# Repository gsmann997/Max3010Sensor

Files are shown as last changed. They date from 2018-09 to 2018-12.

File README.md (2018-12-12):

# Max3010Sensor Build Instruction
# Table of content
1. [Introduction](#introdution)
2. [Parts Required](#parts-required)
3. [Time Commitment](#time-commitment)
4. [OS image and sensor testing](#os-image-and-sensor-testing)
5. [Testing and Pins Soldering](#testing-and-pins-soldering)
6. [Max30105 Electronic File Design](#max30105-electronic-file-design)
7. [Assembly](#assembly)
8. [Code Testing](#code-testing)
9. [Case design and Assembly](#case-design-and-assembly)
10. [Testing](#testing)
<!--
<p>
<img src="https://user-images.githubusercontent.com/43187603/48815301-07242580-ed0c-11e8-836c-ad78ff526679.jpg" heigth=300 width=450>
<p> -->
  img-20181120-wa0004

# Introduction

diagram

This project is based on the MAX30105, which is a very powerful sensor (it can sense the distance, heart rate, particle in the air and even the blinking of an eye)
For this particular project I decided to implement only the heart rate functionality.
It is important that you read the <a href="https://cdn.sparkfun.com/assets/learn_tutorials/5/7/7/MAX30105_3.pdf">datasheet</a> of the sensor before any different connection than the one shown below are done.
For the project I am using the raspberry Pi as microcontroller, as I am already familiar on how it works.
The Max30105 has three on-board LEDs: green, red and IR which works on 5v but the sensor can work on 3.3V as well, as if 5V are applied to the raspberry pi, the GPIO will break.
Below, all the required material, assembly steps and code testing are explained. All the data below has been tested and tried and is the result of many failied attempt. 
It should not take you more than 3h to do everything supposing that you have all the required material.<br>
# Parts required
The Parts required are (click on the product to be redicted where I bought the items, but feel free to buy them from anywhere more convenient to you):
<ul>
  <li><a href="https://www.canakit.com/raspberry-pi-3-model-b-plus-ultimate-kit.html">Raspberry Pi</a></li>
  <li><a href="https://www.amazon.ca/Sandisk-Ultra-Micro-UHS-I-Adapter/dp/B073K14CVB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">Sd card (minimum 8GB)</a></li>
<li><a href="https://www.sparkfun.com/products/14045"> Max30105</a></li>
<li> <a href="https://www.amazon.ca/Haobase-120pcs-Multicolored-Female-Breadboard/dp/B01DLKLL6C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
"> Male to female wires</a></li>
  <li>PCB (my PCB was printed by the <a href="http://munro.humber.ca/~mdrk0011/">prototype lab at Humber College</a> so feel free to use the method more convenient to you)</li>
  <li><a href="https://www.digikey.ca/products/en?keywords=SAM9289-ND">5 Header</a> <a href="https://www.digikey.ca/product-detail/en/sullins-connector-solutions/PPTC051LFBN-RC/S6103-ND/807239">and 6 pin header</a></li>
</ul>
 I spent around 119$ on the parts (<a href="https://github.com/gsmann997/Max3010Sensor/blob/master/documents/budget.xlsx">click here to download my budget</a>). Moreover, consider that it will take around 3/4 weeks to receive the parts, so please take extra time to order and receive the parts.
  
  # Time Commitment
  
  Once you receive that parts (included the PCB), it should take you around 5 hour to do the testing, mechanical assembly and power up.
  Please reference to my <a href= "https://github.com/gsmann997/Max3010Sensor/blob/master/documents/schedule.pdf">time commitment</a> and how I divided the work through 4 months. 
  However, it should not take this much time as I am supplying all required material and a detail guide to follow.
  
  # OS image and sensor testing
Once you received the Raspberry Pi and micro sd, you can proceed to install an OS in the PI.
To install the OS in the PI, reference to <a href="https://github.com/six0four/StudentSenseHat/blob/master/README.md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" >this link </a>, which cointains a detailed guide on how to install an OS in the Pi and has been given to us by our professor.
The second step, after the installion of the OS, is to make the PI accessible either via VNC (<a href="">click here to download vnc for Windows</a>). Activating VNC on the PI does not require much time, I used a guide on 
<a href="https://www.lynda.com/Raspberry-Pi-tutorials/Raspberry-Pi-Essential-Training/667376-2.html">lynda.com</a>, but if you do not have access to lynda.com use any resource.
# Testing and Pins Soldering

Before testing the sensor you need to solder the pins to the sensors. Moreover, before starting any soldering watch <a href="https://www.youtube.com/watch?v=BLfXXRfRIzY&list=PLQ32vZrF5U2lFOJTtZDytBWBYVLNp4RYz"> soldering videos </a> and <a href="https://safety.eng.cam.ac.uk/safe-working/copy_of_soldering-safety"> read risk assessments and chemical safety information</a>
Once you are reading for the soldering, solder the sensor with the pins.
The last step is breadbording and testing the connection/sensor and if every part is working fine.
Follow the wiring diagram below of the wiring:
<div>

</div>
Your breadbord should look like the image below:
<div>

</div>

Once the wiring is done, turn on the pi, enable I2C from options.
Furthermore, open the command terminal and run the following command: <b> i2cdetect -y -1</b><br>
On the screen you should be able to see the address of your sensor, this is a quick test to check if all the wiring has been done properly.
Example of screen:
  
 
# Max30105 Electronic File Design
The final project expects the sensor and the PI to be connected to each other through a PCB. 
I designed my PCB using <a href="http://fritzing.org/download/">fritzing </a>, here you can find <a href="https://github.com/gsmann997/Max3010Sensor/blob/master/documents/myPcb.fzz">my fritzing design</a> and <a href="https://github.com/gsmann997/Max3010Sensor/blob/master/documents/pcb_gerber.zip" >here you can find the gerber file of the PCB</a><br>This is the PCB diagram:

<div>

</div>

Once you get the PCB, you can solder the pins header to the PCB.
This is the final result:

<div>
  
</div> 

# Assembly
Once you receive the PCB, assemble everything:



Then, test it again as you did with the breadboarding <a href="#testing-and-pins-soldering">click here to see the steps again</a>.
# Code Testing
Until now, we have focused only on the hardware part, but we have also to work on the software part.
For the coding part, I used the MAX30102 libraries as I did need only the heart beat and not the other functionality of the sensor.
I have the code uploaded on my github and I am also posting the source code from where I initially retrived it.(
<a href="https://github.com/vrano714/max30102-tutorial-raspberrypi">click here to retrive the code</a> or <a href="https://github.com/gsmann997/Max3010Sensor/tree/master/files">click here for the source code on my github</a>)
Once you upload the code on your raspberry pi, run the max30102.py file with python3 compile option to execute the file and get the RED and IR LED.
# Case design and Assembly
Once the software side is complete the only step remaining is to make and assemble the case.
For the design of the case I used  [CorelDRAW Graphics Suite](https://www.coreldraw.com/en/?link=wm) and you can retrive the design [from here](https://github.com/gsmann997/Max3010Sensor/blob/master/documents/Pi2Case_default.cdr).<br>
Picture of the CorelDraw:<br> 
Once you get the case the only step left is assembling the case.
The final result is:

# Testing
To test if everything works, you can run the code on the PI and verify if the result is acceptable or there are some errors in the output.
As if we try to move this project in a production environment we will need to order everything in bulk which will make everything cheaper, specially the shipping cost. 
To make the production faster we can use one working image and clone it in the other new projects. Moreover, we can check regularly after a number of produced device if the image is working fine and has not been corrupted.
We can automate the soldering and assemblying process. Another improvement could be changing the design of the case and make it easier to assemble. Regarding the case it might be a better option to get it done by an external supplier, instead of buying the raw plastics and using the laser cut to make it.

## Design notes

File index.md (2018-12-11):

# Table of content
1. [week 2](#week-2)
2. [week 3](#week-3)
3. <a href='#week-4'> week 4</a>
4. [week 5](#week-5)
5. [week 7](#week-7)
6. [week 8](#week-8)
7. [week 9](#week-9)
8. [week 10](#week-10)
9. [week 11](#week-11)
10. [week 12](#week-12)
11. [week 13](#week-13)

#### Max3010Sensor
This file contains data for a project involving the Max3010x sensor
## Week 13
The presentation can be found [here](https://github.com/gsmann997/Max3010Sensor/blob/master/documents/MAX30105_presentation.pptx)
## Week 12
This week was due the enclosure.
For this week we had to design and prepare a case for our PI and sensor. To design my case I used [CorelDRAW Graphics Suite](https://www.coreldraw.com/en/?link=wm). After watching some tutorial on how to use the software I was able to modify the sample CorelDraw file ([click here to open it](https://github.com/gsmann997/Max3010Sensor/blob/master/documents/Pi2Case_default.cdr))  our teacher provided for the design.
After I printed the case I noticed that my PCB was overlapping with one side of the case, so I re-cut it with Vlad's help.
Unfortunately, while I was putting it together, I broke the plastic pins that are used to clip in each part of the case, so I had to reprint it again.
Then while I was assembling the new case I accidentaly broke it again. So the next day, I noticed that I was breaking it because of small design issues. After fixing the CorelDraw file and printing it again, finally I put everything together.
Picture of my CorelDraw:
crd
<br><br>Final Design:
img-20181120-wa0004

## Week 11
This week was due the power up milestone.
Unfortunately, as explained in last week posting I was already running late on my [schedule]( https://github.com/gsmann997/Max3010Sensor/blob/master/documents/schedule.pdf) and I have not been able to meet the deadline.
I tried to look up libraries for the integration of my sensor and the Pi but I was not able find anything.
The next step I took was looking up code online to get an idea of the type of code I need to write for my sensor.
However, not being familiar with this type of task made the whole process slower and time consuming.
So after I wrote my code, I tested it and unfortunatly It was not working. 
Then I tried to change approach, therefore I read the arduino libraries to get an idea of what I need but it has not been helpful.
In class I consulted the teacher and he advised me to take a smaller step and try to turn on the read LED on the sensor and look up all the register on the [datasheet](https://cdn.sparkfun.com/assets/learn_tutorials/5/7/7/MAX30105_3.pdf) of the sensor.
Moreover, I wrote some testing code but the reading on the screen was 0 and was not changing which meant It was not working.
After, I asked the teacher what I could do to fix the problem.
He advised me to test the code on another sensor: PCF8591.
Now, my next goals are going to be: learn how to push/ pull data from/to the PCF8591, write the code for the max30105 to get the readings within next week.
Regarding the [budget](https://github.com/gsmann997/Max3010Sensor/documents/budget.xlsx) no extra expenses where made.

# Update: 
After consulting Vlad from the prototype lab I decided to keep working on my sensor before trying to use the PCF8591, and after a couple more hours of research I find out that the previous version of my sensor (MAX30102) and the one I am using (MAX30105) are compatible.
The only difference between the two version is the fact that the older one does not have the green LED. However, the heart beat reading are calculated from the RED and IR LED.
After a couple more hours I was able to find a compatible library for my sensor on github([click here to retrive the code](https://github.com/vrano714/max30102-tutorial-raspberrypi) or [click here for the source code on my github](https://github.com/gsmann997/Max3010Sensor/tree/master/files)). Therefore, I installed and run the code.
Conclusion: I have been able to pull data from my sensor, but I still have to make the code I got mine.<br>
Next Goal: <br>   - Send the case to the prototype lab
           <br>   - Get ready for next week enclosure
<br>Below are the pictures of the code I run:<br><br>
redlog
<br><br>This are the readings I get from the RED LED<br><br>
irlog
<br><br>This are the readings I get from the IR LED<br><br>
graph
<br><br>Included in the files I got online, there was also a file to graph the two readings from the sensor.<br><br>

## Week 10
This week was due the PCB soldering. As advised by our teacher, I soldered headers to my PCB instead of soldering my sensor and the PI directly to the PCB, as if the PCB would not have worked I could have replaced the PCB instead of unsoldering everything.
Regarding the headers, in my last week posting I mentioned that I would be reaching out Kelly from the prototype lab for the headers. However, even though he provided me the headers for free, he did not have the 6x2 and 5x1 pin headers so he gave me bigger ones. 
Fortunately, I was able cut both the headers to fit my requirements.
My [budget](https://github.com/gsmann997/Max3010Sensor/documents/budget.xlsx)  did not see major changes thanks to the help of the prototype lab.
So my final result is:
pcb
pi pcb

The next step after the soldering is testing. 
I tested the PCB using the i2c detect command and everything worked.
proofofpcb
<br><br>Next week is the power up milestone for which we have to push or pull data from/to the sensor.
For this milestone I am actually one week behind [schedule]( https://github.com/gsmann997/Max3010Sensor/blob/master/documents/schedule.pdf) so as a partial solution of this I am going to try to get it done in one week and be ready for next week milestone. 
Moreover, I was able to ask the teacher a question regarding the implementation of the software intended to read/write from the sensor, as there are no library available for the integration of the MAX30105 with the raspberry pi; so the professor advised me to implement the code for the sensor.
In conclusion the next step is being able to pull the raw data from the sensor.<br>
## Week 9
This week I designed the PCB using Fritzing ([click here to download the fritzing file of the pcb](https://github.com/gsmann997/Max3010Sensor/blob/master/documents/myPcb.fzz)) and submitted [Gerber file](https://github.com/gsmann997/Max3010Sensor/blob/master/documents/pcb_gerber.zip) for the printing to the prototype lab.
During the design of the PCB I spent a lot of time while trying to find a compatible connector/sensor that will have the same pins as the one I am using. However I was not sure about the distance between pins so with more research I was actually able to find my sensors fritzing part online. <br><br>
pcb
# Progress Report:
So far everything is going as planned, even though I spent more time than what was necessary on the designing of the PCB, and I am behind schedule on the software part of the project (get readings from the sensor).<br>
This week I am going to try to catch on the schedule and go to the prototype lab to ask for help on the software part.<br>
My budget may see some changment with some extra cost due the fact that I am going to use two stackable headers: one of 6 pin and one of 5 pin to be able to get more modularity and versatility on my project, so even if my PCB will not work I will be able to design and use another one faster.
For this extra cost I have to see Vlad and Kelly from the prototype lab as they might have extra headers in the lab.
## Week 8
Breadboard milestone was due in this week (see picture below). <br>
Moreover, we had to check if everything is on track or not.
After meeting with my team member and checking the work done so far, I can say me and my team member are going as planned and we are meeting the goal set. Unfortunately I received my sensor late which left me behind with the soldering. However, I had already watched tutorial and practiced in class. 
So thanks to Vlad and Kelly I was able to catch up quickly.
So far no extra cost was required.
breadboard_milestone
Before doing the breadboarding I prepared a fritzing diagram (my sensor was not available in fritzing so I used another sensor with the same Pin):<br>
<br>
drawing_scheme<br>
## Week 7
This week we did the soldering. Unfortunately due to shipping issue I could not solder the pins in class. 
However, I received the part the next day and got it soldered in the prototype lab with the help of Vlad.
<br>
Pseudo-code was also written to get an idea of what code we will have to write for the power up
pseudo-code
## Week 5
## Proof of purchase
**Raspberry Pi**
pi_invoice
**Wires**<br>
wires_receipt
**MAX3010x Pulse & Oximetry sensor (0x57)**
heart_beat
## Week 4
## Schedule
budjet_image
## Week 3
During the third week we planed our future steps and organized how to progress with the project.
schedule_image
[schedule.pdf](https://github.com/gsmann997/Max3010Sensor/files/2508397/schedule.pdf)
### Week 2
This week I meet up with my group member and prepared the proposal.
proposal

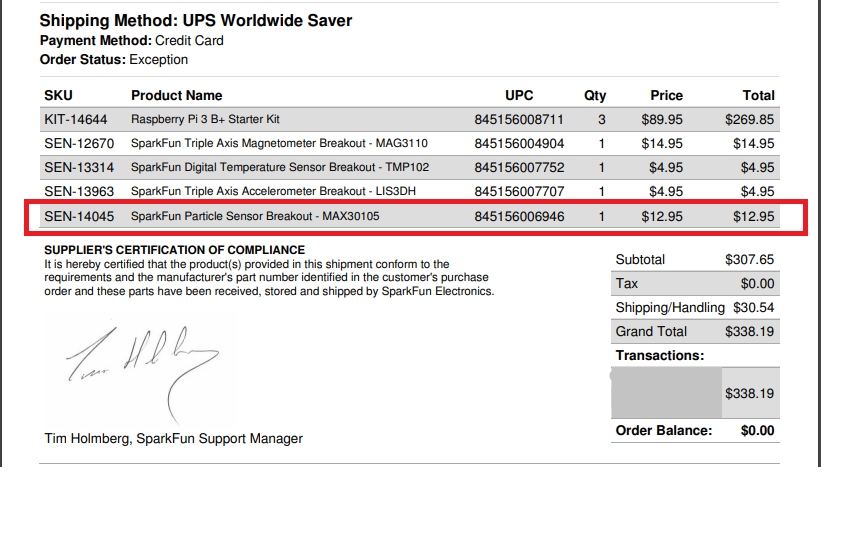
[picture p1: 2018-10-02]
Invoices/heart_beat.png

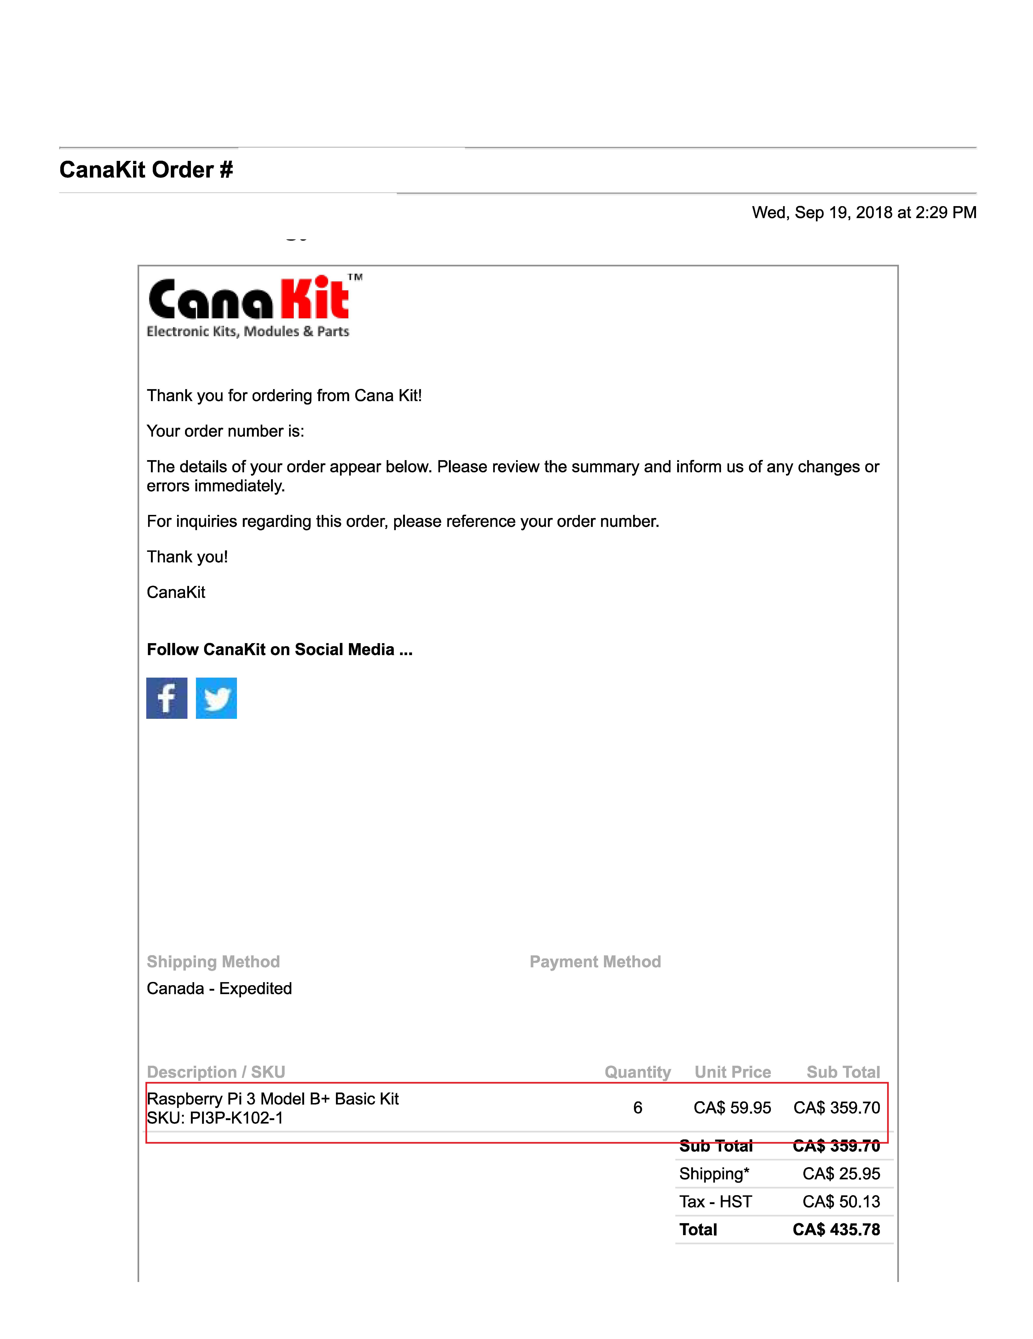
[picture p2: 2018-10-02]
Invoices/Pi_invoice.jpg

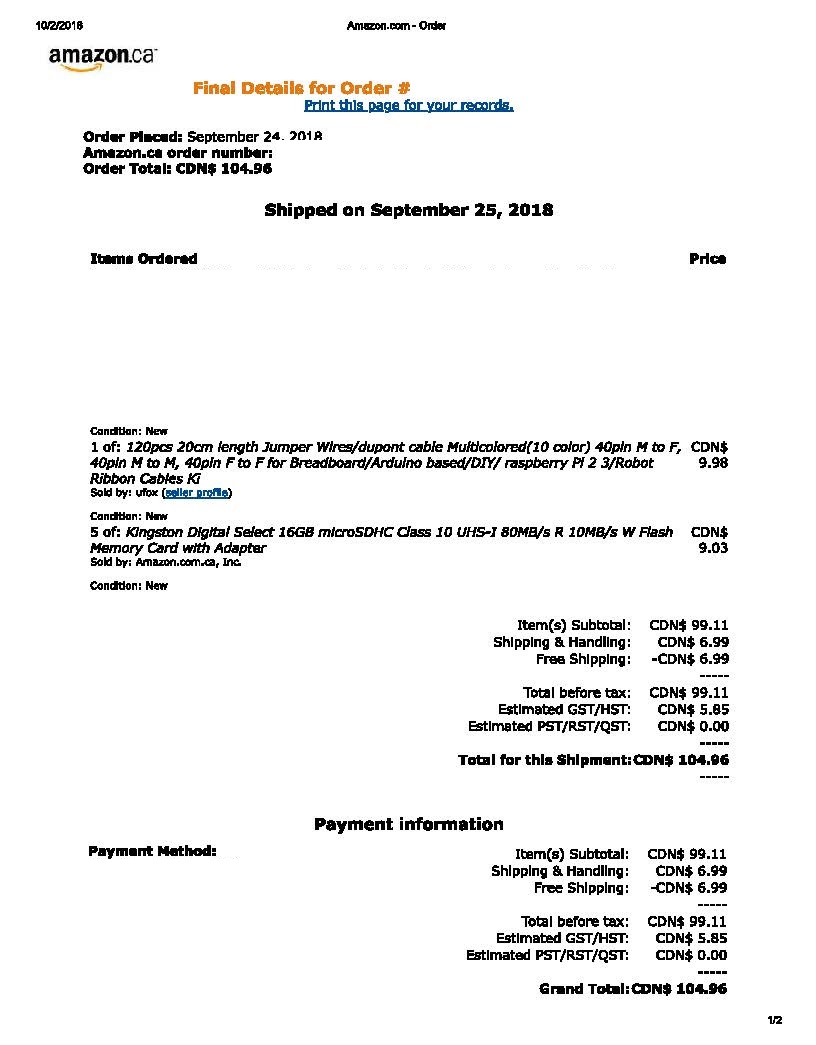
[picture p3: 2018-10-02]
Invoices/Wires_receipt.jpg

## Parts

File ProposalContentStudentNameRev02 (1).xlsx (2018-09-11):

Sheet: DataEntry
Submission Date | 2018-11-09
Project Name | SensorEffector
Student Name | Singh Gurpreet
Project repository | https://github.com/gsmann997/Max3010Sensor
SensorEffector choice | MAX3010x Pulse & Oximetry sensor (0x57)
The database will store | The pulse and oximetry's reading
The mobile device functionality will include | The possibility of accessing the reading of the sensor
I will be collaborating with the following company/department
My group in the winter semester will include | Kuljeet singh, saini sahil
50 word problem statement | There are many reasons why the heart beat increases such as:high blood pressure, coronary artery disease, heart valve disease and many more, for which monitoring heart pulse may help in preventing any further complication. Moreover, many more issues
100 words of background
Current product APA citation
Existing research IEEE paper APA citation
Brief description of planned purchases
Solution description

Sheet: DataBase
Submission Date | Project Name | Student Name | Project repository | SensorEffector choice | The database will store | The mobile device functionality will include | I will be collaborating with the following company/department | My group in the winter semester will include | 50 word problem statement | 100 words of background | Current product APA citation | Existing research IEEE paper APA citation | Brief description of planned purchases | Solution description
43413 | SensorEffector | Singh Gurpreet | https://github.com/gsmann997/Max3010Sensor | MAX3010x Pulse & Oximetry sensor (0x57) | The pulse and oximetry's reading | The possibility of accessing the reading of the sensor | Kuljeet singh, saini sahil | #REF! | There are many reasons why the heart beat increases such as:high blood pressure, coronary artery disease, heart valve disease and many more, for which monitoring heart pulse may help in preventing any further complication. Moreover, many more issues | 0 | 0 | 0 | 0 | 0

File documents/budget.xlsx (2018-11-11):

Singh Gurpreet
Budget for Heart & oximetry sensor
Item | Supplier and part # | Description | Link | Quantity | Price per unit (CDN) | Subtotal | taxes | shipping | total
Raspberry Pi 3 Model B+ Basic Kit | canakit | Microcontroller used to control sensor | https://www.canakit.com/raspberry-pi-3-model-b-plus-basic-kit.html | 1 | $59.95 | $59.95 | $7.80 | $3.00 | $70.75
SparkFun Particle Sensor Breakout - MAX30105 | sparkfun | Sensor used for heart beat and oximetry readings | https://www.sparkfun.com/products/14045 | 1 | $16.77 | $16.77 | $2.18 | $5.30 | $24.25
Jumper wires | Amazon | Used to make raspberry and sensor wiring on breadboard | https://www.amazon.ca/Haobase-120pcs-Multicolored-Female-Breadboard/dp/B01DLKLL6C | 1 | $9.99 | $9.99 | $1.30 | FREE | $11.29
Sandisk Ultra 16GB Micro | Amazon | Store raspberry pi OS | https://www.amazon.ca/Sandisk-Ultra-Micro-UHS-I-Adapter/dp/B073K14CVB?s=electronics | 1 | $12.05 | $12.05 | $1.57 | FREE | $13.62
Plastic for case | Humber College (Prototype Lab) | Plastic used to make case for raspberry pi | n/a | n/a | n/a | n/a | n/a | n/a | n/a
PCB | Humber College (Prototype Lab) | Used to make the finising product more compact | n/a | 1 | n/a | n/a | n/a | n/a | n/a
6 pin header | Humber College (Prototype Lab) | Used to connect pi to the PCB (for modularity) | n/a | 1 | n/a | n/a | n/a | n/a | n/a
5 pin header | Humber College (Prototype Lab) | Used to connect sensor to the PCB (for modularity) | n/a | 1 | n/a | n/a | n/a | n/a | n/a
Total |  |  |  |  |  |  |  |  | $119.91
